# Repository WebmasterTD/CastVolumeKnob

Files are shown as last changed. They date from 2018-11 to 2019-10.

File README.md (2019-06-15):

# CastVolumeKnob

is hardware volume control for Chromecast Audio devices, based on the ESP8266 microcontroller using micropython.

## The problem

For controlling the volume on Chromecast devices you need to use your phone. - it is clumsy, not very intuitive.

## The requirements

* Easy to use, hardware based volume control.
* Wireless
* Visual feedback of the current volume level
* Relatively cheap

## The solution

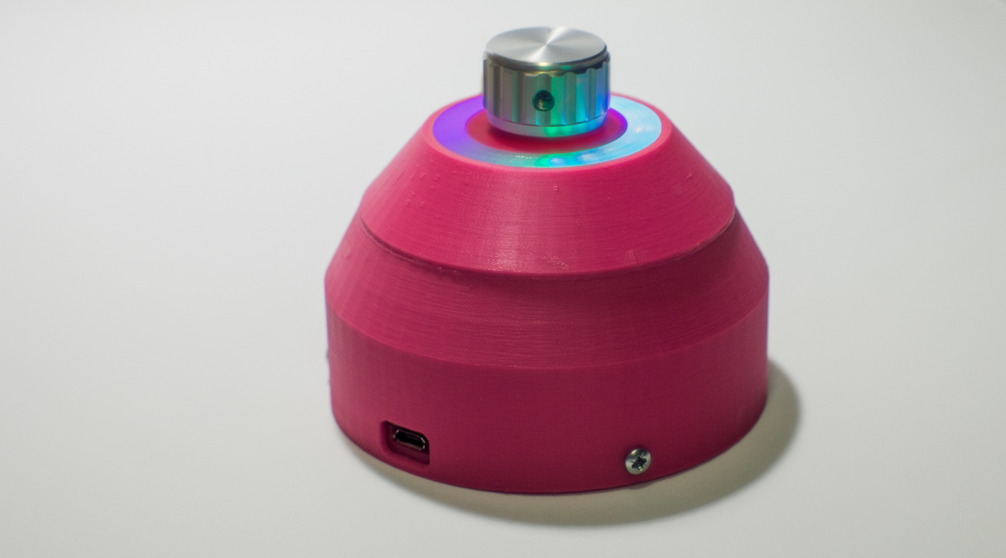
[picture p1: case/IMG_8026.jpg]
CastVolumeKnob


This is the final form. Completely wireless, rechargeable device. 

To wake it up you have to tap the knob once. After it wakes up it automatically connects to the first chromecast device, you can control its volume by turning the knob. To change the device tap the knob again. To stop the music playback press and hold the knob until the LEDs turn red.

## Instructions:

### Schematic

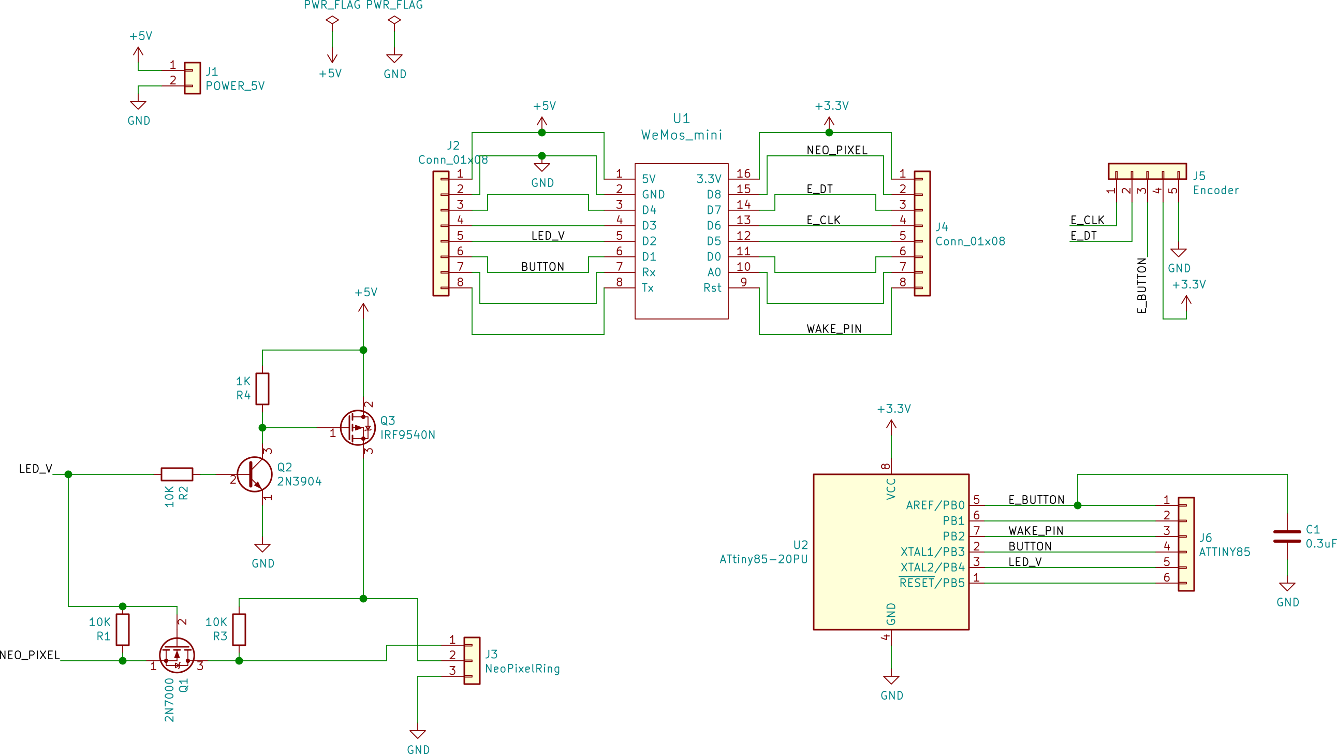
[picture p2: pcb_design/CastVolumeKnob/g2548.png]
Schematic


### Programming the ESP8266

* install esptool and ampy
    ```shell
    pip install esptool
    pip install adafruit-ampy
    ```

* erase the flash with esptool
    ```shell
    esptool.py --port COM5 erase_flash
    ```
* download the micropython firmware

    [MicroPython](http://micropython.org/download#esp8266)

* deploy the firmware
    ```shell
    esptool.py --port COM5 --baud 460800 write_flash --flash_size=detect 0 esp8266-20170108-v1.8.7.bin
    ```

* Configuring wificonf.py

* put the code to the mcu
    ```shell
    ampy -p COM5 -b 115200 put     main.py
                    boot.py
                    encoder.py
                    wificonf.py
                    volume.py
    ```

### Assembly

* 3D print the case and glue the middle and the top part together
* Solder everything to the PCB
* Put the LED ring and Encoder in place
* Screw the Board in place
* Solder the Battery holder to the charging/boost converter board
* Glue it in place
* Screw the bottom part in

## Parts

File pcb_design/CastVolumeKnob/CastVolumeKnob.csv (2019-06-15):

Id | Designator | Package | Quantity | Designation | Supplier and ref
1 | J1 | PinHeader_1x02_P2.54mm_Horizontal | 1 | POWER_5V
2 | Q1 | TO-92_Inline | 1 | 2N7000
3 | R1,R2,R3 | R_Axial_DIN0207_L6.3mm_D2.5mm_P10.16mm_Horizontal | 3 | 10K
4 | J5 | PinHeader_1x05_P2.54mm_Horizontal | 1 | Encoder
5 | J3 | PinHeader_1x03_P2.54mm_Horizontal | 1 | NeoPixelRing
6 | J2,J4 | PinHeader_1x08_P2.54mm_Vertical | 2 | Conn_01x08
7 | U1 | wemos-d1-mini-connectors-only | 1 | WeMos_mini
8 | Q2 | TO-92_Inline | 1 | 2N3904
9 | , | MountingHole_3.2mm_M3_ISO14580_Pad | 2
10 | C1 | C_Disc_D3.8mm_W2.6mm_P2.50mm | 1 | 0.3uF
11 | J6 | PinHeader_1x06_P2.54mm_Vertical | 1 | ATTINY85
12 | R4 | R_Axial_DIN0207_L6.3mm_D2.5mm_P10.16mm_Horizontal | 1 | 1K
13 | U2 | DIP-8_W7.62mm_Socket_LongPads | 1 | ATtiny85-20PU
14 | Q3 | TO-220-3_Horizontal_TabDown-132 | 1 | IRF9540N

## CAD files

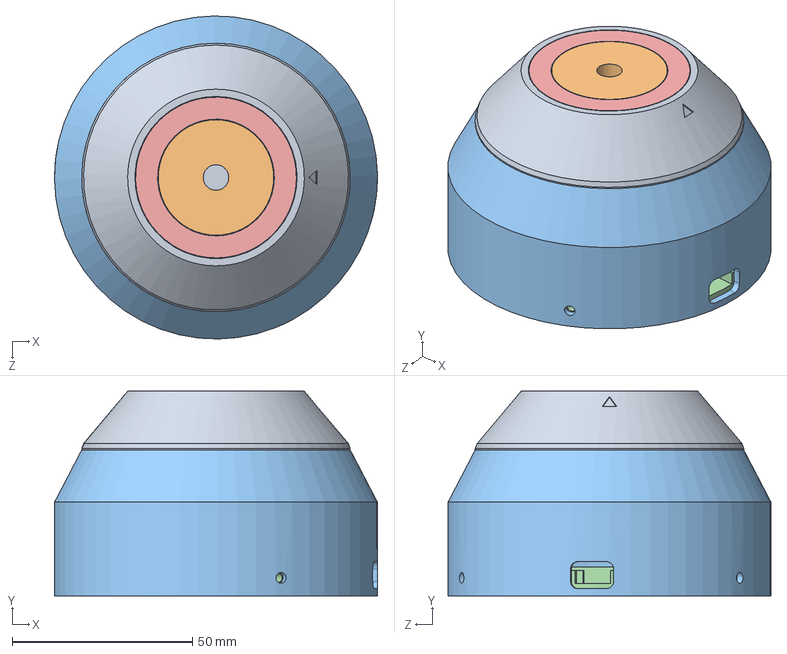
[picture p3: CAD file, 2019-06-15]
case/Chromecast.SLDASM
89.6 x 56.8 x 89.6 mm
cast_board_cover
Test04a
cast_board_side3
cast_board_bottom
cast_led_cover

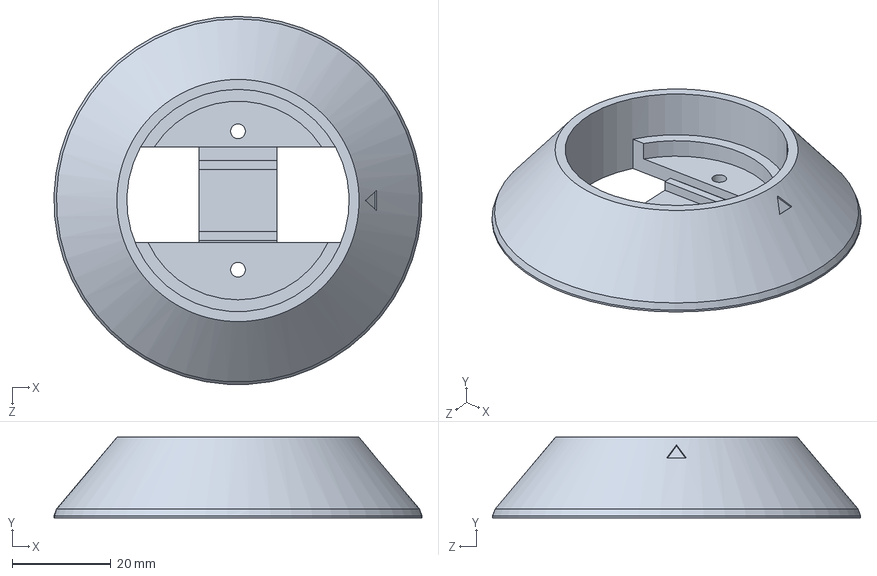
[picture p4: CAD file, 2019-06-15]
case/cast_board_cover.SLDPRT
74.5 x 16.3 x 74.5 mm

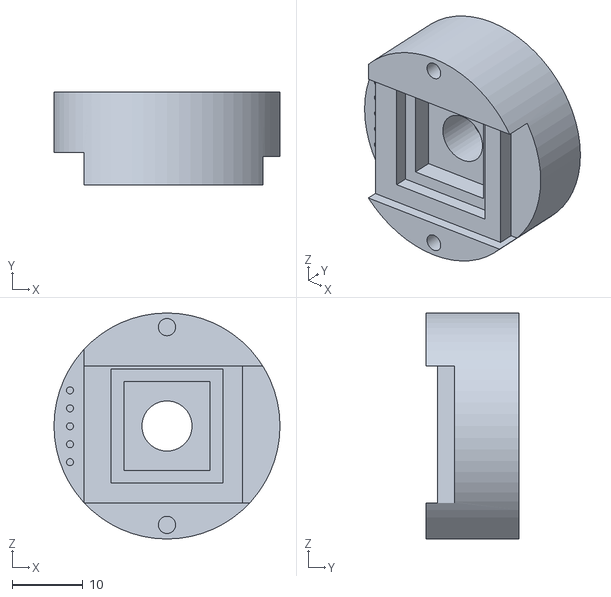
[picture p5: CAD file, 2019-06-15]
case/stl/CAST_TOP_COVER02.STL
32.0 x 13.1 x 32.0

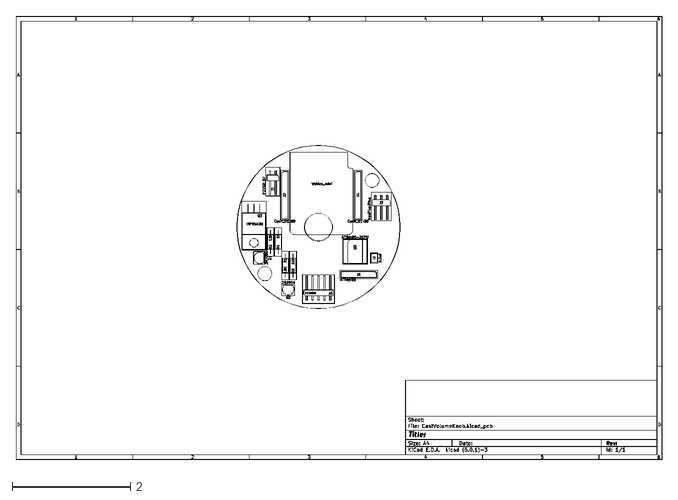
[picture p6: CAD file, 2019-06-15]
pcb_design/CastVolumeKnob/CastVolumeKnob-brd.dxf
10.9 x 7.49

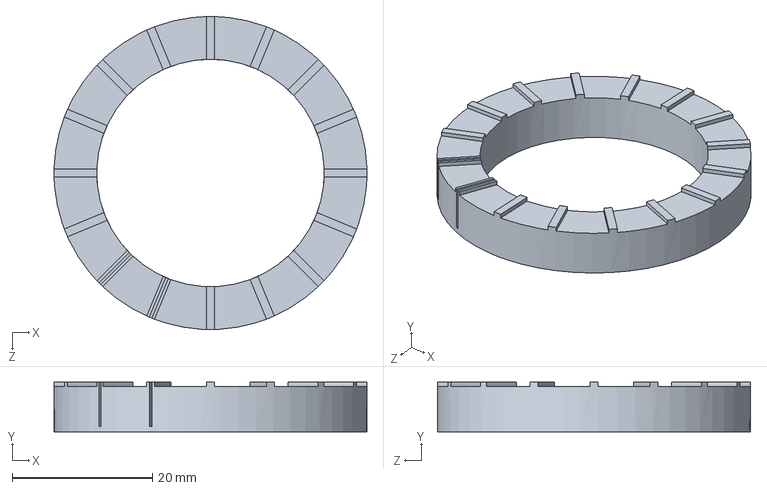
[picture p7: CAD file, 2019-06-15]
case/cast_led_cover.SLDPRT
44.6 x 7.10 x 44.6 mm

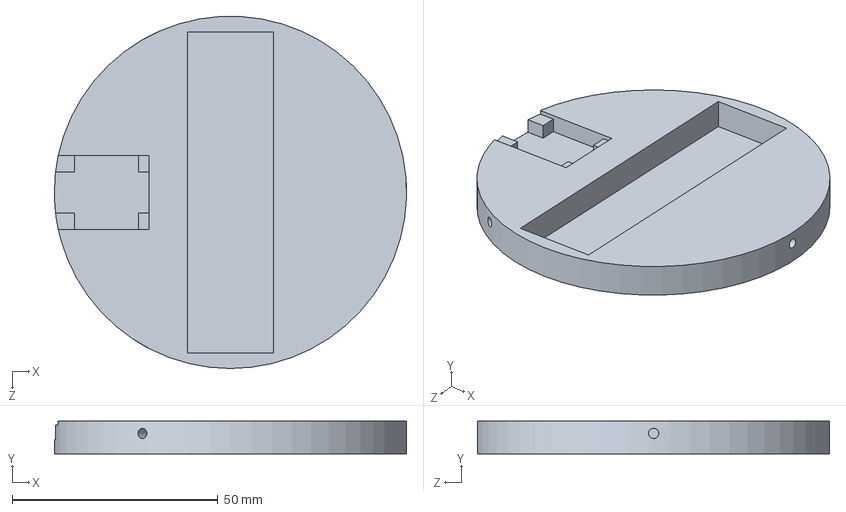
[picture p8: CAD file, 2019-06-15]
case/cast_board_bottom.SLDPRT
85.6 x 8.00 x 85.5 mm

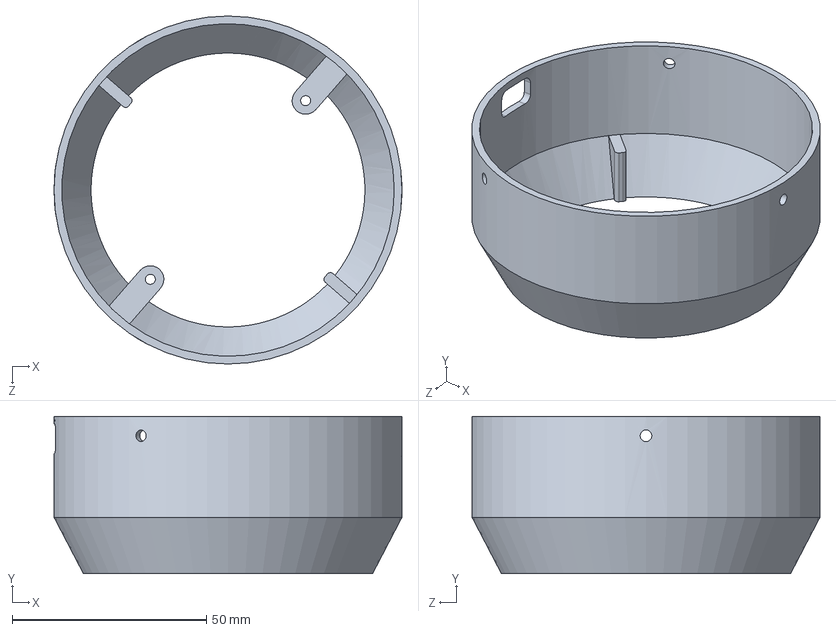
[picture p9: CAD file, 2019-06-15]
case/cast_board_side3.SLDPRT
89.6 x 40.5 x 89.6 mm

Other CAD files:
case/stl/CAST_TOP02.STL
case/Test04a.SLDPRT
case/stl/cast_board_bottom.STL
case/stl/cast_board_side3.STL
case/stl/cast_led_cover.STL

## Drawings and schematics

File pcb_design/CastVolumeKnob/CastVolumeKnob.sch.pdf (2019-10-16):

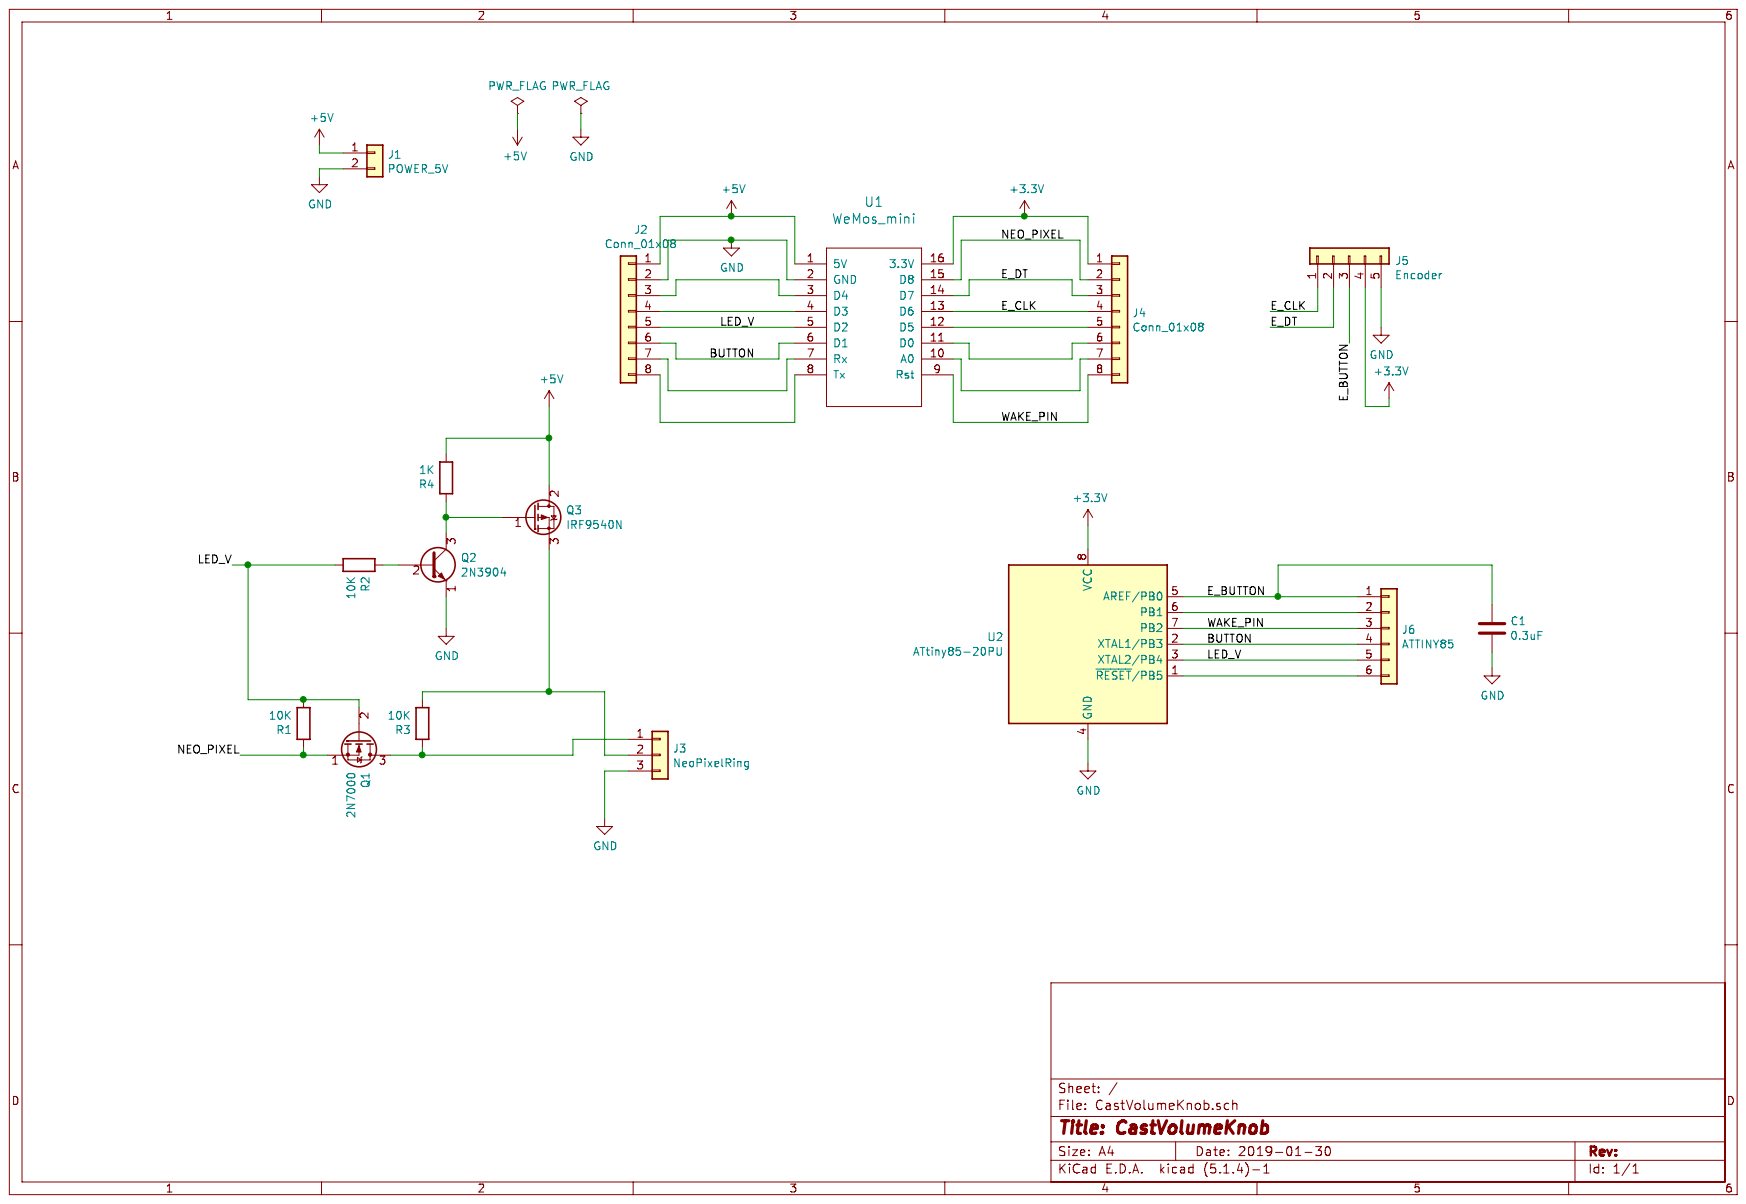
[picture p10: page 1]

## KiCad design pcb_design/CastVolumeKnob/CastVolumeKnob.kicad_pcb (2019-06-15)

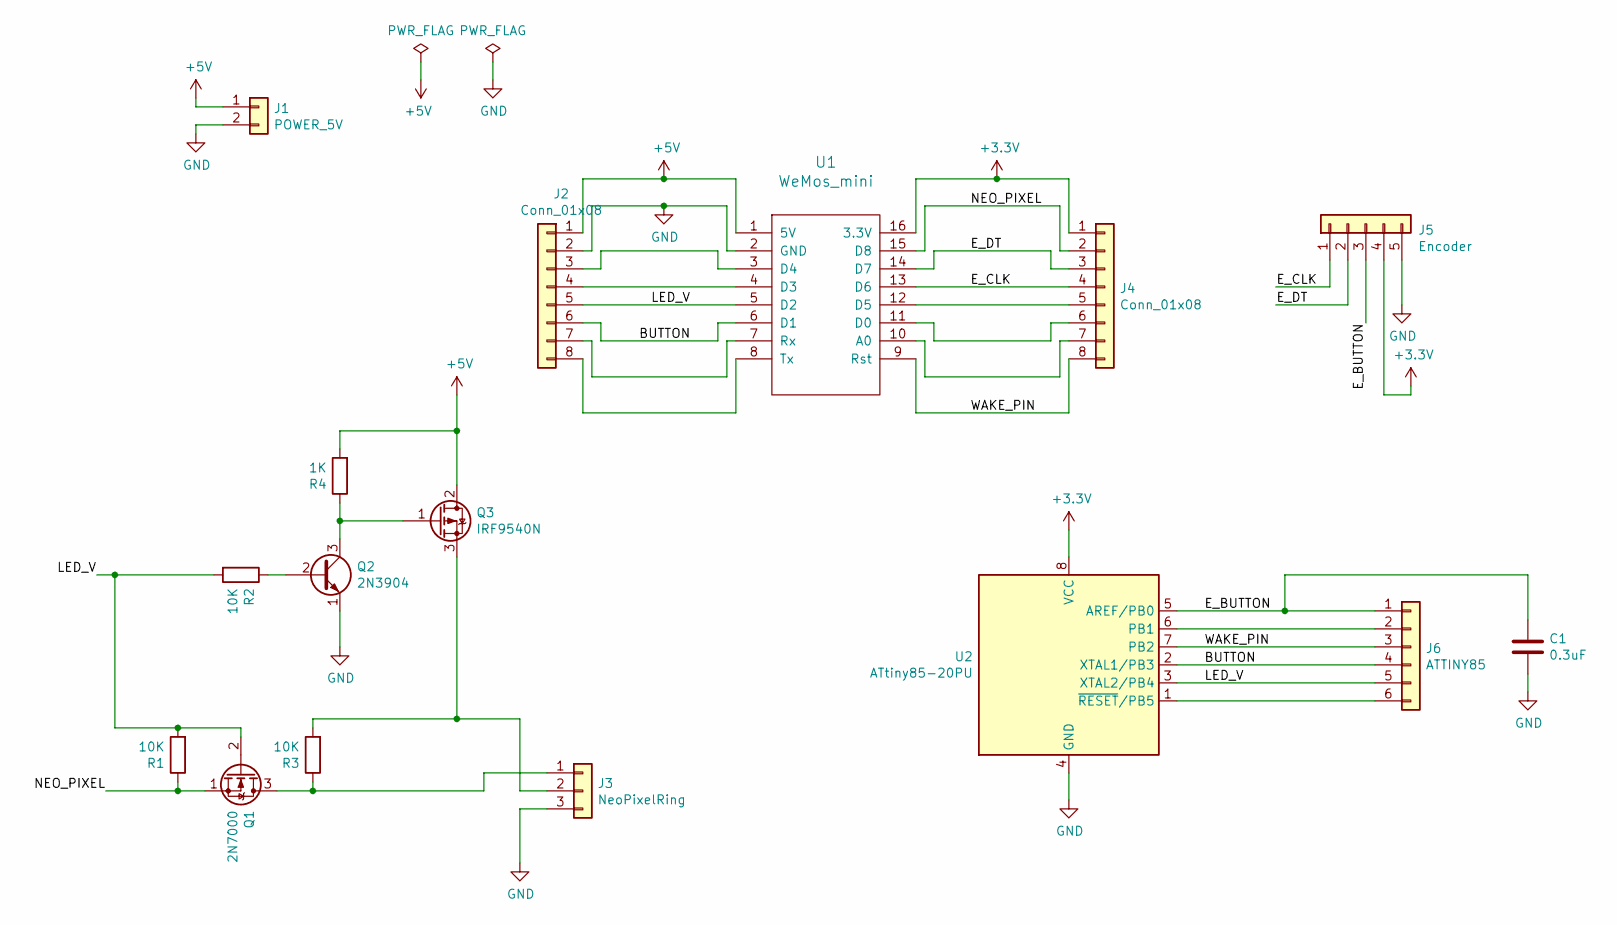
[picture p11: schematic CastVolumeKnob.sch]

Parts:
C1: 0.3uF; C_Disc_D3.8mm_W2.6mm_P2.50mm
J1: POWER_5V; PinHeader_1x02_P2.54mm_Horizontal
J2, J4: Conn_01x08; PinHeader_1x08_P2.54mm_Vertical
J3: NeoPixelRing; PinHeader_1x03_P2.54mm_Horizontal
J5: Encoder; PinHeader_1x05_P2.54mm_Horizontal
J6: ATTINY85; PinHeader_1x06_P2.54mm_Vertical
Q1: 2N7000; TO-92_Inline
Q2: 2N3904; TO-92_Inline
Q3: IRF9540N; TO-220-3_Horizontal_TabDown-132
R1, R2, R3: 10K; R_Axial_DIN0207_L6.3mm_D2.5mm_P10.16mm_Horizontal
R4: 1K; R_Axial_DIN0207_L6.3mm_D2.5mm_P10.16mm_Horizontal
U1: WeMos_mini; wemos-d1-mini-connectors-only
U2: ATtiny85-20PU; DIP-8_W7.62mm_Socket_LongPads

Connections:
+3V3: J4.1, J5.4, U1.16 (3.3V), U2.8 (VCC)
+5V: J1.1, J2.1, Q3.2 (D), R4.2, U1.1 (5V)
/BUTTON: J2.6, J6.4, U1.6 (D1), U2.2 (XTAL1/PB3)
/E_BUTTON: C1.1, J5.3, J6.1, U2.5 (AREF/PB0)
/E_CLK: J4.4, J5.1, U1.13 (D6)
/E_DT: J4.3, J5.2, U1.14 (D7)
/LED_V: J2.5, J6.5, Q1.2 (G), R1.2, R2.2, U1.5 (D2), U2.3 (XTAL2/PB4)
/NEO_PIXEL: J4.2, Q1.1 (S), R1.1, U1.15 (D8)
/WAKE_PIN: J4.8, J6.3, U1.9 (Rst), U2.7 (PB2)
GND: C1.2, J1.2, J2.2, J3.3, J5.5, Q2.1 (E), U1.2 (GND), U2.4 (GND)
unnamed: J2.3, U1.3 (D4)
unnamed: J2.4, U1.4 (D3)
unnamed: J2.7, U1.7 (Rx)
unnamed: J2.8, U1.8 (Tx)
unnamed: J3.1, Q1.3 (D), R3.1
unnamed: J3.2, Q3.3 (S), R3.2
unnamed: J4.5, U1.12 (D5)
unnamed: J4.6, U1.11 (D0)
unnamed: J4.7, U1.10 (A0)
unnamed: J6.2, U2.6 (PB1)
unnamed: J6.6, U2.1 (~RESET~/PB5)
unnamed: Q2.2 (B), R2.1
unnamed: Q2.3 (C), Q3.1 (G), R4.1

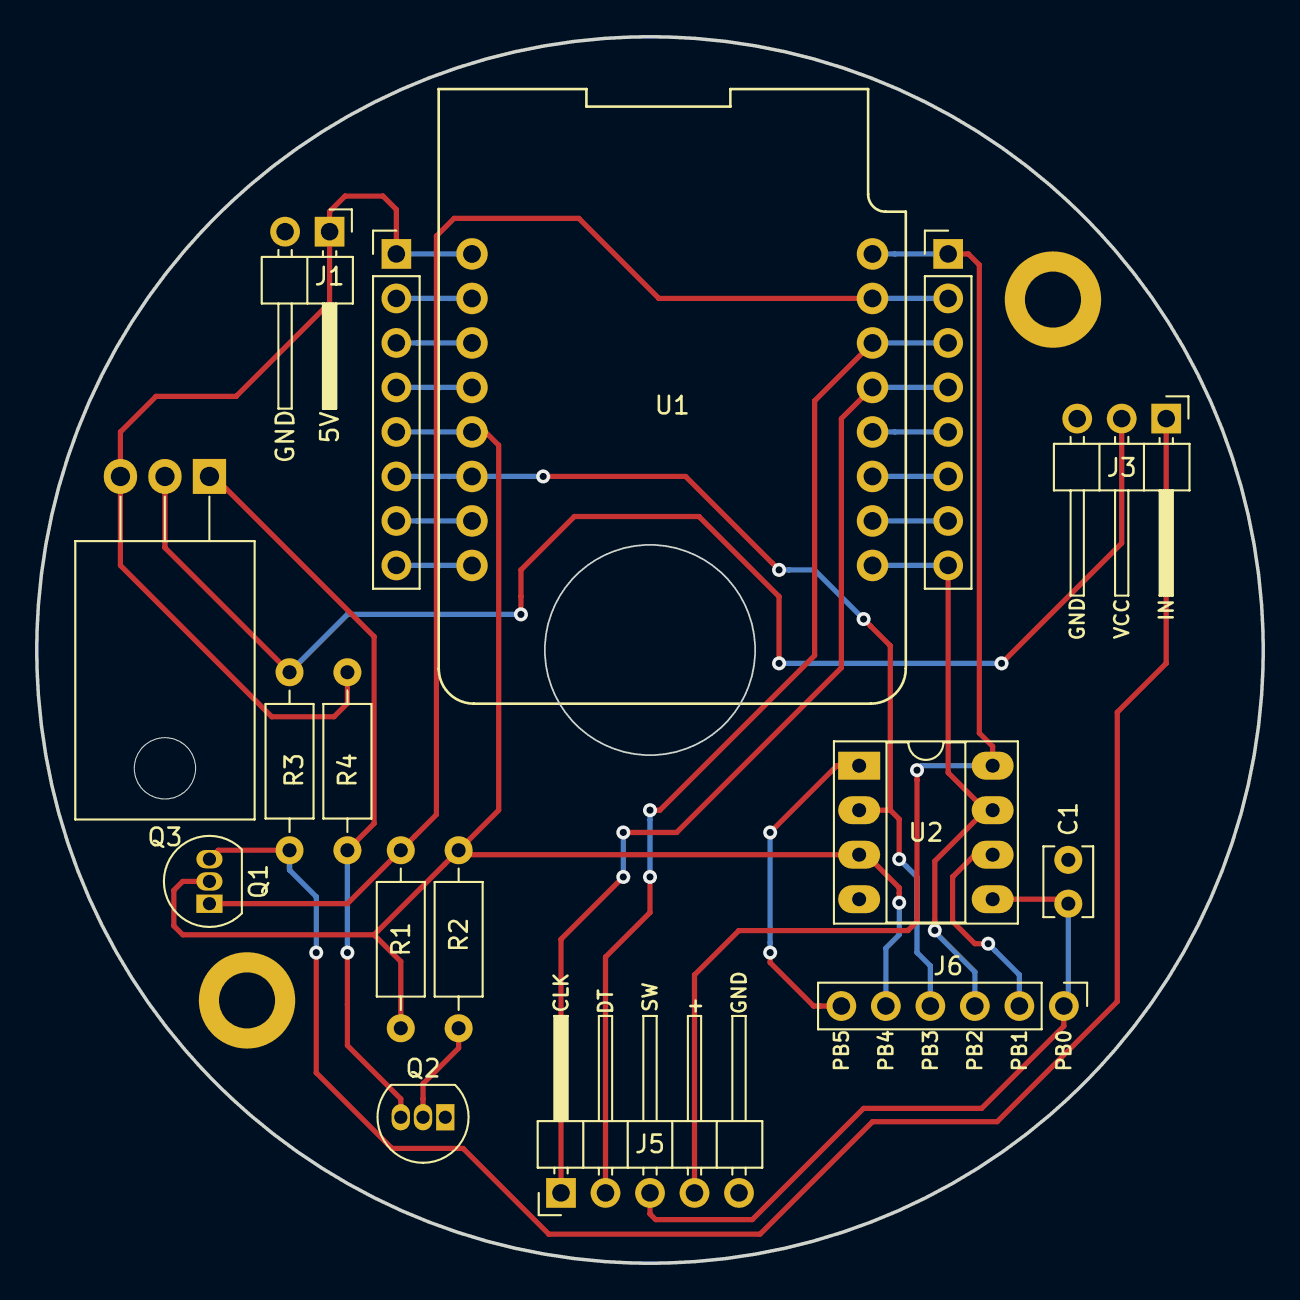
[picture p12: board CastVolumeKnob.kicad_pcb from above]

Board: 2 copper layers, 70.0 x 70.0 mm, 16 parts (0 on the bottom side), 23 nets.

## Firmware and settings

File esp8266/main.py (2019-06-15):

from encoder import Encoder
import utime as time
import machine
import esp
import volume
import wificonf
import uerrno

cast_ip = list(wificonf.CHROMECASTS.keys())

cast_name  = wificonf.CHROMECASTS

def cycle(p):
    """
    Makes a generator cycling through arg p 
    """
    try:
        len(p)
    except TypeError:
        # len() is not defined for this type. Assume it is
        # a finite iterable so we must cache the elements.
        cache = []
        for i in p:
            yield i
            cache.append(i)
        p = cache
    while p:
        yield from p

chromecast = cycle(cast_ip)

device = next(chromecast)

def connect2device(np):
    """
    Connects to cast device and returns an instance of the device.
    If can't connect to the device, pops it from the cast_ip list 
    and switches to the next device
    """
    global device
    connected = False
    while not connected:
        try:
            cast = volume.Chromecast(device)
            connected = True
        except OSError as err:
            if err.args[0] == uerrno.ECONNABORTED:
                new_device = next(chromecast)
                np.error()
                print('ERROR CONNECTING TO: ', cast_name[device])
                cast_ip.pop(cast_ip.index(device))
                del cast_name[device]
                device = new_device
                
    return cast

def main():
    global device
    device = next(chromecast)
    enc = Encoder(12, 13, clicks=2, reverse=True)
    np = volume.NeoPixelRing(4, device, machine.Pin(15), 16)
    button = machine.Pin(5, machine.Pin.IN)
    cast = connect2device(np)
    current_vol = cast.get_volume
    print('Connected to:', cast_name[device], device, 'current vol:', current_vol)
    enc.set_val(current_vol)
    last_enc_val = current_vol
    last_change_tick = time.ticks_ms()
    np.change_device(device, current_vol)
    
    while True:
        val = enc.value
        if last_enc_val != val:
            print(val)
            np.set_vol(val)
            last_enc_val = val
            last_change_tick = time.ticks_ms()

        #CHANGING VOLUME    
        if (time.ticks_diff(time.ticks_ms(), last_change_tick) > 200) and (last_enc_val != current_vol):
            cast.set_volume(val)
            current_vol = cast.get_volume
            print('current volume:', current_vol)

        #SLEEP AFTER DELAY
        if (time.ticks_diff(time.ticks_ms(), last_change_tick) > 10000): #10 sec
            cast.disconnect()
            np.turn_off()
            print("SLEEP")
            esp.deepsleep()
        
        #CHANGING CHROMECAST WITH ENCODER BUTTON
        if button.value():
            print('BUTTON PRESSED')
            b_start = time.ticks_ms()
            while button.value():
                if (time.ticks_diff(time.ticks_ms(), b_start) > 2000):
                    print('STOPPING PLAYBACK')
                    np.stop()
                    cast.stop_playback()
                    time.sleep_ms(1500)
                    np.set_vol(current_vol)
                    last_change_tick = time.ticks_ms()
                    break
            if time.ticks_diff(time.ticks_ms(), b_start) < 2000:
                cast.disconnect()
                prev_device = device
                device = next(chromecast)
                if device is not prev_device:
                    cast = connect2device(np)
                    current_vol = cast.get_volume
                    enc.set_val(current_vol)
                    np.change_device(device, current_vol)
                    print('switched to:', cast_name[device], device, 'current vol:', current_vol)
                last_change_tick = time.ticks_ms()

        time.sleep_ms(100)

if __name__ == '__main__':
    main()

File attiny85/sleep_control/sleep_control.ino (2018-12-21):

#include <avr/interrupt.h>
#include <avr/sleep.h>
#include <Time.h>

#define WAKE_PIN 2
#define LED_V_PIN 4
#define INT_PIN 0
#define BUTTON 3

volatile int state = 30;

void setup() {
  GIMSK = 0b00100000;
  PCMSK = 0b00000001;
  ADCSRA &= ~_BV(ADEN);                   
  
  //Serial.begin(9600);
  pinMode(WAKE_PIN, OUTPUT);
  digitalWrite(WAKE_PIN, HIGH);
  pinMode(LED_V_PIN, INPUT);
  pinMode(BUTTON, OUTPUT);
  pinMode(INT_PIN, INPUT_PULLUP);
 
  cli();
  //attachInterrupt(digitalPinToInterrupt(INT_PIN), wake_up, LOW);
  }

void loop() {
  switch (state) {
    case 0:   //reset ESP 
      rst_esp();
      state = 10;
      break;
      
    case 5:   //TEST case
      delay(1000);
      state = 30;
      break;
      
    case 10:    //WAIT for ESP to turn on
      while (digitalRead(LED_V_PIN) == LOW) {
        delay(50);
      }
      state = 20;
      break;

    case 20:    //RUNNING --- WAIT for ESP to turn off     
      while (digitalRead(LED_V_PIN) == HIGH) {
        if (digitalRead(INT_PIN) == LOW) {
            digitalWrite(BUTTON, HIGH);
            while (digitalRead(INT_PIN) == LOW) {
              delay(50);
            }
            digitalWrite(BUTTON, LOW);
        }
        delay(50);
        //Serial.println(state);
      }
      state = 30;
      break;      
    case 30:
      //attachInterrupt(digitalPinToInterrupt(INT_PIN), wake_up, LOW);
      sei();
      state = 40;
      break;
    case 40:
      sleep();
  }
  delay(100);

}

ISR(PCINT0_vect)
{
  cli();
  state = 0;
}

void rst_esp() {
  digitalWrite(WAKE_PIN, LOW);
  delay(500);
  digitalWrite(WAKE_PIN, HIGH);
}

void sleep() {
    cli();
    set_sleep_mode(SLEEP_MODE_PWR_DOWN);    // replaces above statement
    sleep_enable();                         // Sets the Sleep Enable bit in the MCUCR Register (SE BIT)
    sei();                                  // Enable interrupts
    sleep_cpu();                            // sleep
    } 

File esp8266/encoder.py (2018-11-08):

# -*- coding: utf-8 -*-
"""MicroPython rotary encoder library.

Usage:

    from time import sleep_ms
    from encoder import Encoder

    # Connect CLK to D6, DT to D5, GND to GND and + to 3V3
    enc = Encoder(pin_clk=12, pin_dt=14)

    def readloop(e):
        oldval = 0
        while True:
            val = enc.value
            if oldval != val:
                print(val)
                oldval = val
            sleep_ms(50)

    readloop(e)
"""

from machine import Pin


ENC_STATES = (
    0,   # 00 00
    -1,  # 00 01
    1,   # 00 10
    0,   # 00 11
    1,   # 01 00
    0,   # 01 01
    0,   # 01 10
    -1,  # 01 11
    -1,  # 10 00
    0,   # 10 01
    0,   # 10 10
    1,   # 10 11
    0,   # 11 00
    1,   # 11 01
    -1,  # 11 10
    0    # 11 11
)
ACCEL_THRESHOLD = const(5)


class Encoder(object):
    def __init__(self, pin_clk, pin_dt, pin_mode=None, clicks=1,
                 min_val=0, max_val=100, accel=0, reverse=False):
        self.pin_clk = (pin_clk if isinstance(pin_clk, Pin) else
                        Pin(pin_clk, Pin.IN, pin_mode))
        self.pin_dt = (pin_dt if isinstance(pin_dt, Pin) else
                       Pin(pin_dt, Pin.IN, pin_mode))

        self.min_val = min_val * clicks
        self.max_val = max_val * clicks
        self.accel = int((max_val - min_val) / 100 * accel)
        self.max_accel = int((max_val - min_val) / 2)
        self.clicks = clicks
        self.reverse = 1 if reverse else -1

        # The following variables are assigned to in the interrupt callback,
        # so we have to allocate them here.
        self._value = 0
        self._readings = 0
        self._state = 0
        self.cur_accel = 0

        self.set_callbacks(self._callback)

    def _callback(self, line):
        self._readings = (self._readings << 2 | self.pin_clk.value() << 1 |
                          self.pin_dt.value()) & 0x0f

        self._state = ENC_STATES[self._readings] * self.reverse

        if self._state:
            self.cur_accel = min(self.max_accel, self.cur_accel + self.accel)

            self._value = min(self.max_val, max(self.min_val, self._value +
                              (1 + (self.cur_accel >> ACCEL_THRESHOLD)) *
                              self._state))

    def set_callbacks(self, callback=None):
        mode = Pin.IRQ_RISING | Pin.IRQ_FALLING
        self.irq_clk = self.pin_clk.irq(trigger=mode, handler=callback)
        self.irq_dt = self.pin_dt.irq(trigger=mode, handler=callback)

    def close(self):
        self.set_callbacks(None)
        self.irq_clk = self.irq_dt = None

    @property
    def value(self):
        return self._value // self.clicks

    def reset(self):
        self._value = 0

    def set_val(self, val):
        new_val = self.clicks * int(val)
        if new_val >= self.min_val or new_val <= self.max_val:
            self._value = new_val
        elif new_val < self.min_val:
            self._value = self.min_val
        elif new_val > self.max_val:
            self._value = self.min_val
        else:
            pass

def test(enc=None, **kwargs):
    from time import sleep_ms
    rate = kwargs.pop('rate', 20)

    if not isinstance(enc, Encoder):
        cls = kwargs.pop('encoder_cls', Encoder)
        kwargs.setdefault('pin_clk', 12)
        kwargs.setdefault('pin_dt', 14)
        kwargs.setdefault('clicks', 4)
        enc = cls(**kwargs)

    oldval = 0
    try:
        while True:
            val = enc.value
            if oldval != val:
                print(val)
                oldval = val

            enc.cur_accel = max(0, enc.cur_accel - enc.accel)
            sleep_ms(1000 // rate)
    except:
        enc.close()

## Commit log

2018-10-08 added esp encoder library
2018-10-29 added set fuction to encoder
2018-11-04 added led indicators
2018-11-04 basic arduino interrupt
2018-11-07 KiCaD project created
    [CastVolumeKnob.kicad_pcb, CastVolumeKnob.sch]
2018-11-11 arduino interrupt wake up
2018-11-11 Cleaned up code, MOSFET led switch
2018-11-11 KiCad schematic changes
    [CastVolumeKnob.sch]
2018-11-11 Kicad on linux
    [CastVolumeKnob.sch]
2018-11-14 led Mosfet control baked into neo pixel class
2018-11-14 Improved schematics
    [CastVolumeKnob.sch]
2018-11-18 Interrupt misfiring fix
2018-11-18 schematic fixes
    [CastVolumeKnob.sch]
2018-11-25 PCB schematic changes
    [CastVolumeKnob.sch]
2018-11-29 volume init bug fixed
    [volume.py]
2018-12-02 Added switch button mode
2018-12-02 Button switch test
2018-12-02 PCB v01 - oredered version
    [CastVolumeKnob-B.Cu.gbl, CastVolumeKnob-B.Mask.gbs, CastVolumeKnob-B.SilkS.gbo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]
2018-12-08 switch between chromecasts with encoder button
2018-12-09 change device color
2018-12-20 Added button press time
2018-12-23 WORKING VERSION static ip, bug fixes
    [boot.py, main.py, volume.py]
2019-01-01 Fixed mosfet footprint for v2 pcb
    [CastVolumeKnob-brd.dxf, CastVolumeKnob.kicad_pcb, CastVolumeKnob.sch]
2019-01-27 Added 3D files and README
    [CAST_TOP02.STL, CAST_TOP_COVER02.STL, CastVolumeKnob.csv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]
2019-01-30 Updated Schematic
    [CastVolumeKnob-B.Cu.gbl, CastVolumeKnob-B.Mask.gbs, CastVolumeKnob-B.SilkS.gbo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]
2019-01-30 JPG Schematic
2019-10-07 add .pdf of schematic and layout
